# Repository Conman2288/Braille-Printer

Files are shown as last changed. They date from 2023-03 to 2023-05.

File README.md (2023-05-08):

# Braille-Printer
Our project is a personal braille printer with the aim of being one of the cheaper options on the market. The reason that we chose this as our project is because current braille printers cost, on average, over $1,000. By making a more affordable version, we can make braille more accessible for the blind, which is a step towards giving this community a better quality of life. The way that our project works is by using an embosser that moves along a lead screw. This embosser has a set of multiple braille states that are essentially specific bumps that can be switched to on command. A flexible roller is then rolled over the desired state, with the paper in between, in order to emboss the braille onto the paper. The program running on the machine is able to take in a text or pdf file and scan the words in the file. It takes these words and converts them into braille characters, which are then split into their multiple braille states, as each character is made up of two different states. These braille states are then sent to the printer, where, line by line, the braille characters are embossed into the piece of paper. This all comes together to make a device that can receive text input and subsequently print out braille characters, making braille printing accessible at a lower cost than is currently on the market.

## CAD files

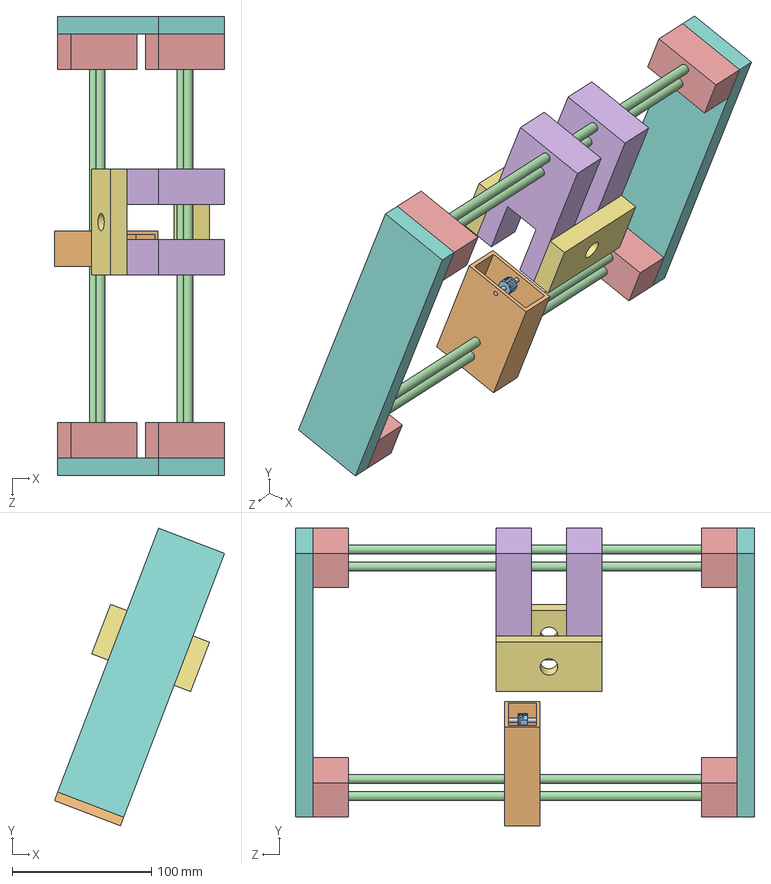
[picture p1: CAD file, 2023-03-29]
Version 2/Final Assembly 2.0.SLDASM
122.4 x 214.1 x 330.2 mm
Roller Axle 2.0
Roller Holder 2.0
Braile Roller 2.0
Leadscrew 2.0 x 4
Pillow Block 2.0 x 4
Wheel Holder 2.0 x 2
Shoulder Bearing 2.0 x 2
Main Holder x 2

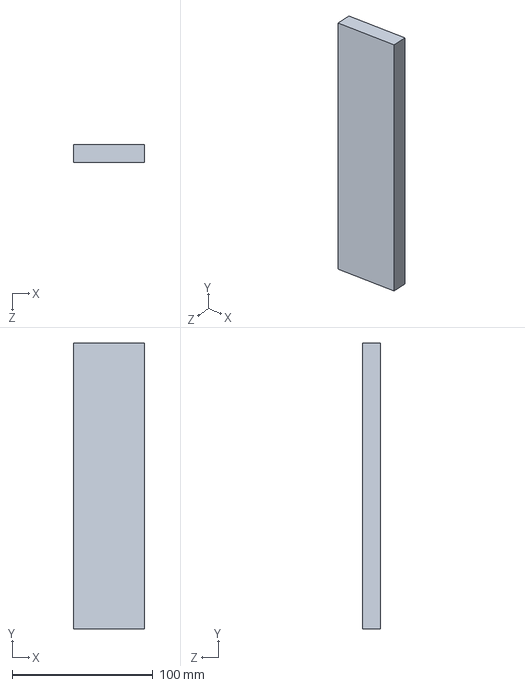
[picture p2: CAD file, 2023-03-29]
Version 2/Main Holder.SLDPRT
50.8 x 203.2 x 12.7 mm

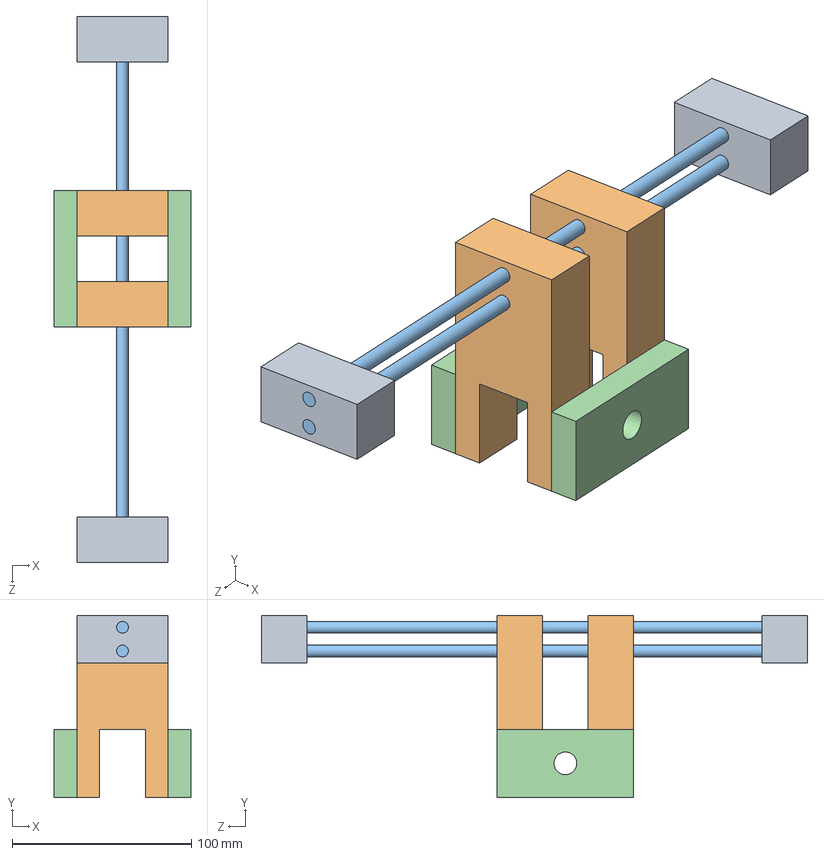
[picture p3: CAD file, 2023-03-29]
Version 2/Wheel assembly 2.0.SLDASM
76.2 x 101.6 x 304.8 mm
Pillow Block 2.0 x 2
Wheel Holder 2.0 x 2
Leadscrew 2.0 x 2
Shoulder Bearing 2.0 x 2

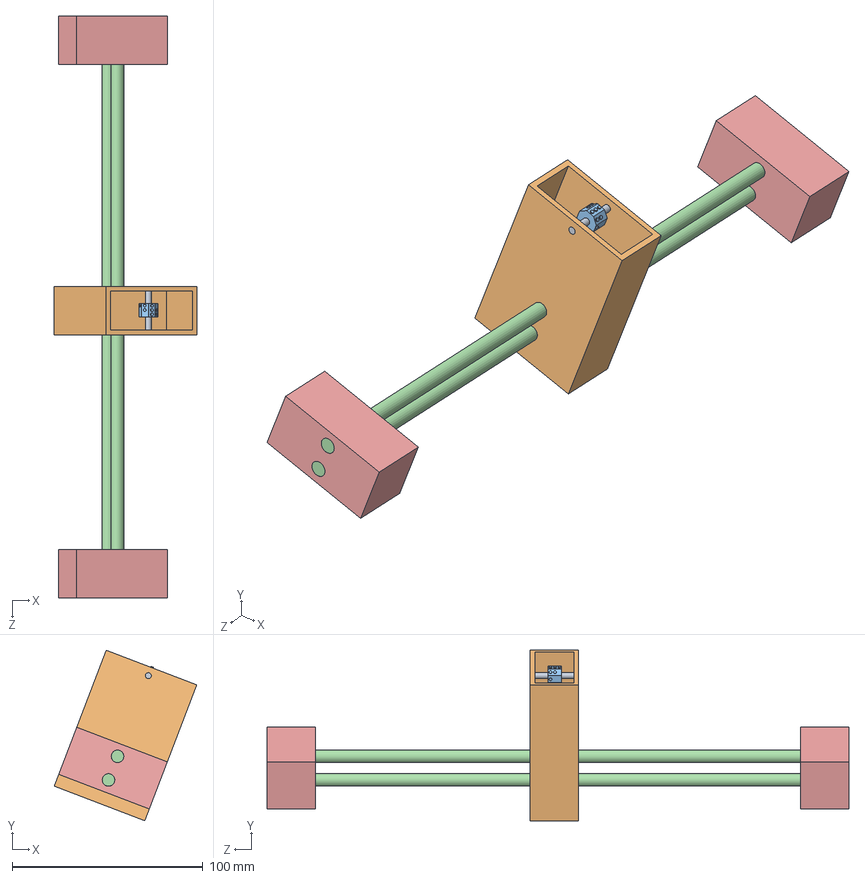
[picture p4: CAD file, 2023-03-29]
Version 2/Presser Assambly.SLDASM
74.7 x 89.3 x 304.8 mm
Roller Axle 2.0
Roller Holder 2.0
Braile Roller 2.0
Leadscrew 2.0 x 2
Pillow Block 2.0 x 2

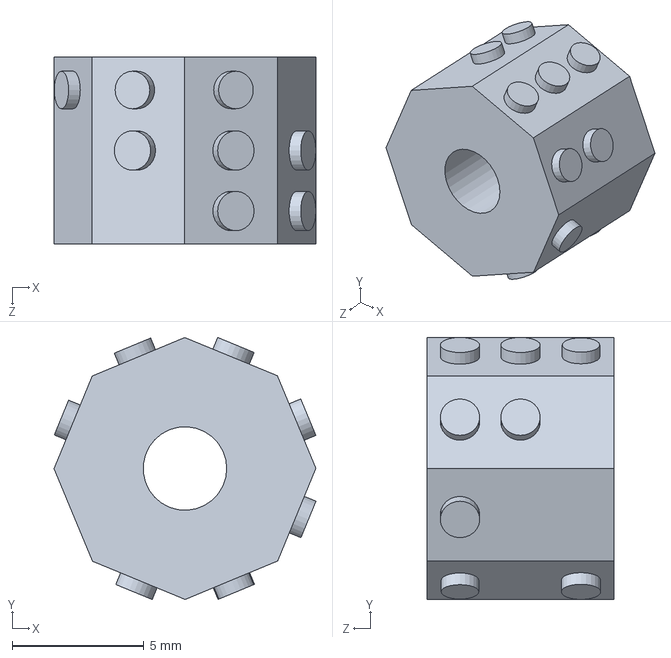
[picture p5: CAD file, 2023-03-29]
Version 2/Braile Roller 2.0 .SLDPRT
9.96 x 9.96 x 7.10 mm

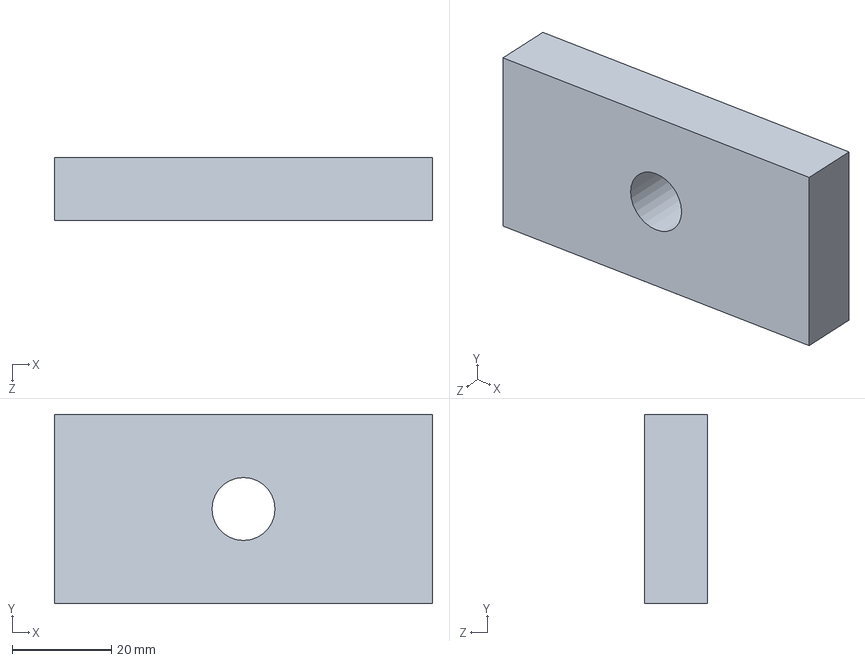
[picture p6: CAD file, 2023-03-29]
Version 2/Shoulder Bearing 2.0.SLDPRT
76.2 x 38.1 x 12.7 mm

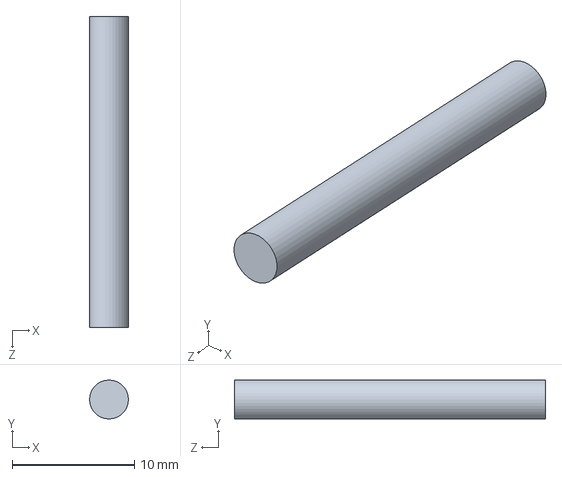
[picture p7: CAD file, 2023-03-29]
Version 2/Roller Axle 2.0.SLDPRT
3.17 x 3.17 x 25.4 mm

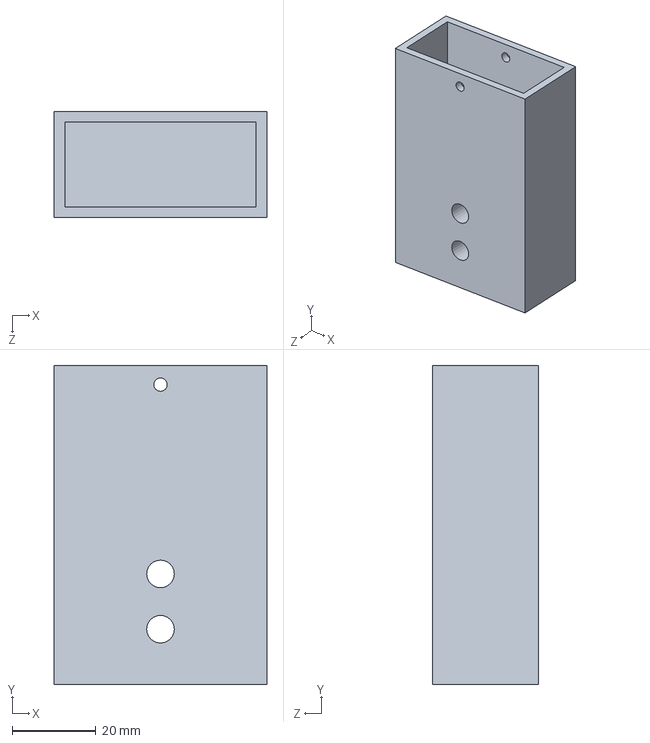
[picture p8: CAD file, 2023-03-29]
Version 2/Roller Holder 2.0.SLDPRT
50.8 x 76.2 x 25.4 mm

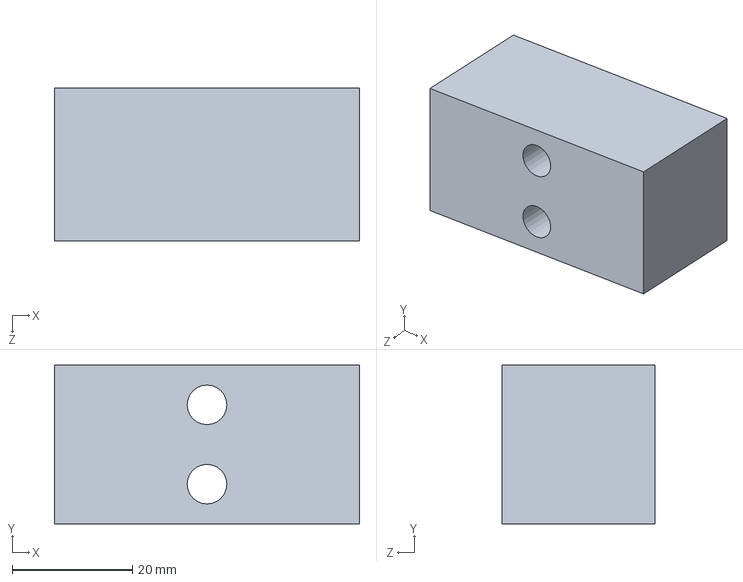
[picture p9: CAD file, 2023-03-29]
Version 2/Pillow Block 2.0.SLDPRT
50.8 x 26.4 x 25.4 mm

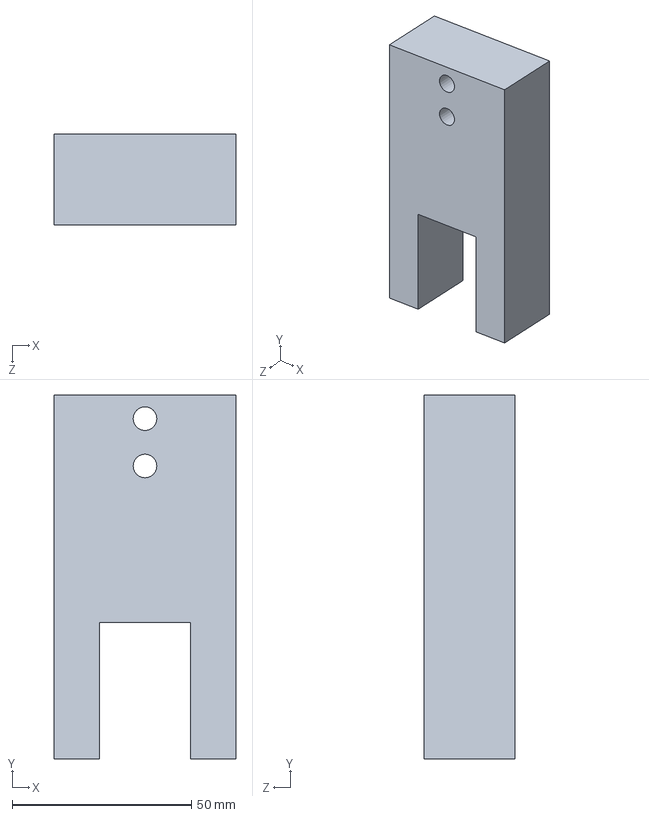
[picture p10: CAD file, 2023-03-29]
Version 2/Wheel Holder 2.0.SLDPRT
50.8 x 101.6 x 25.4 mm

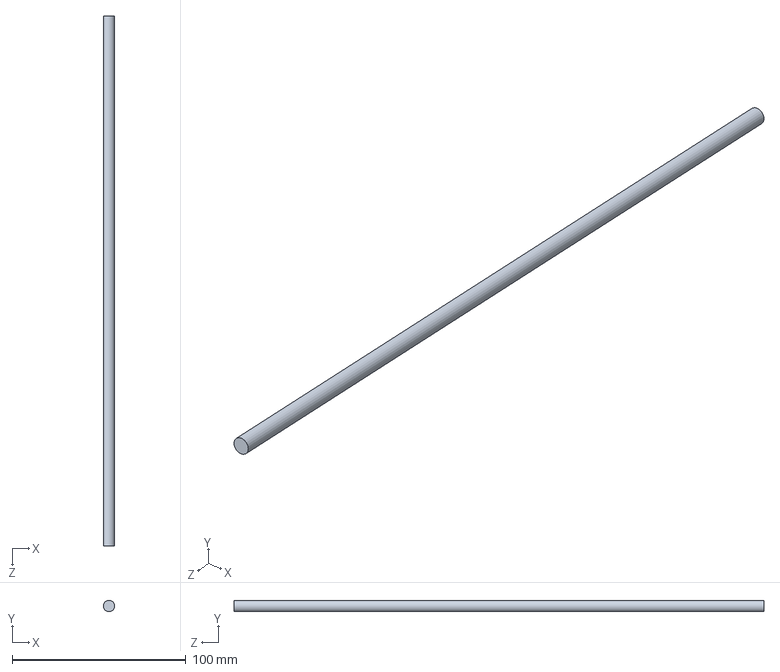
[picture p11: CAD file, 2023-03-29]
Version 2/Leadscrew 2.0.SLDPRT
6.60 x 6.60 x 304.8 mm

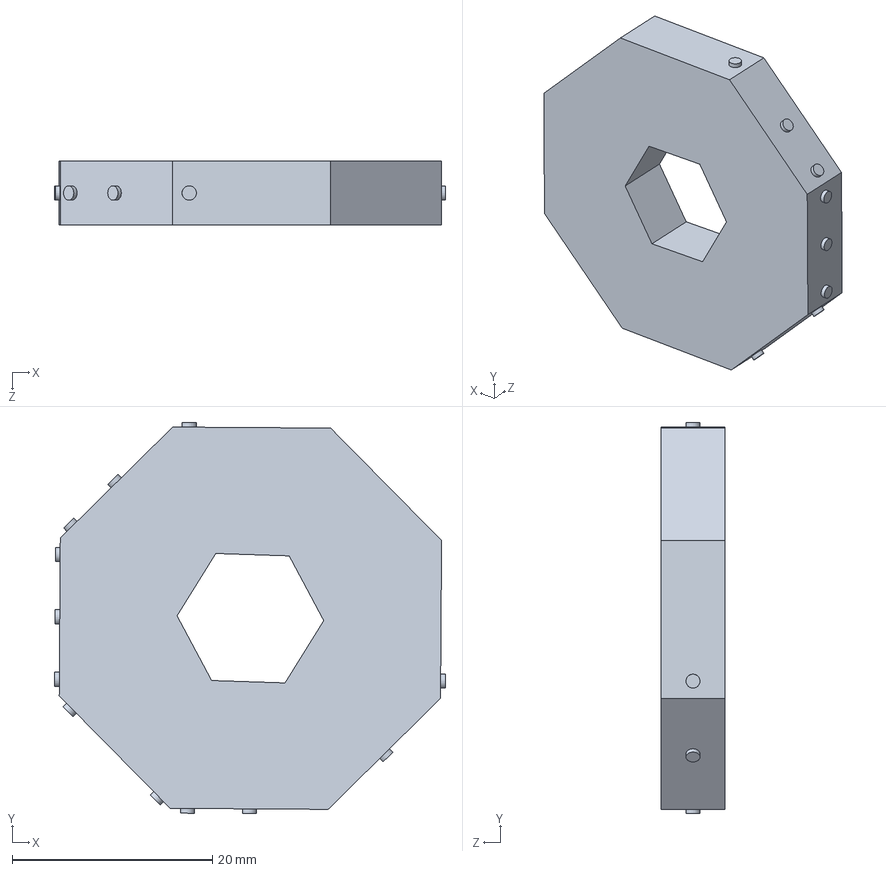
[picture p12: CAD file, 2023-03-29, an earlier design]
Version 1/BraillePresser Part 1.SLDPRT
39.1 x 39.1 x 6.35 mm

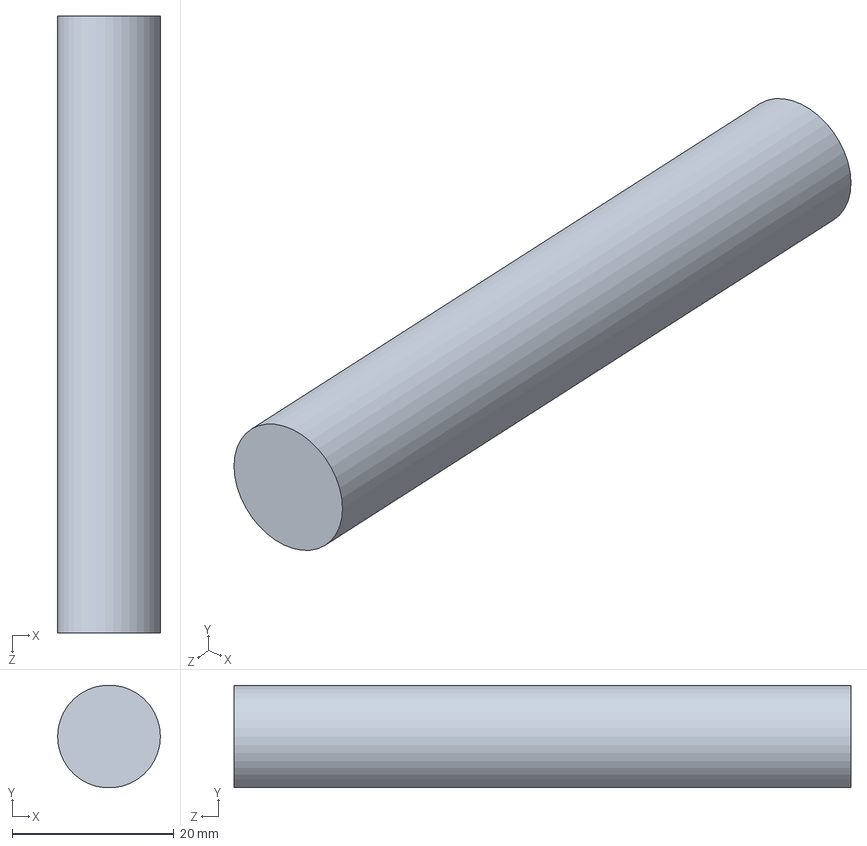
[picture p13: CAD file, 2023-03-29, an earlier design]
Version 1/Wheel Axle.SLDPRT
12.7 x 12.7 x 76.2 mm

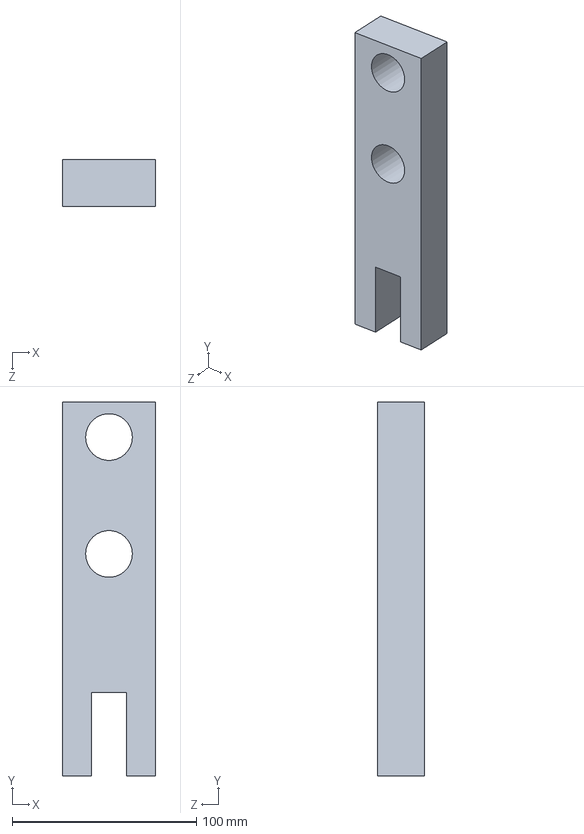
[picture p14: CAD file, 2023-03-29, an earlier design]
Version 1/Wheel holder.SLDPRT
50.8 x 203.2 x 25.4 mm

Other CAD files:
Version 1/Side plate wheel.SLDPRT
Version 1/Initial Assembly - Leadscrew portion.SLDASM
Version 1/leadscrew.SLDPRT
Version 1/Leadscrew Holder.SLDPRT
Version 2/Braile Roller 2.0 .STL

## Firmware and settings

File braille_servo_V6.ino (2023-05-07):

#include <Servo.h>

Servo servo;
int servo_pin = 3;
int motor_pin = 5;
int servo_rotation_count = 0; // variable to count the number of times the servo has rotated
int enA = 7;         // Motor connections
int in1 = 8;
int in2 = 9;
int in3 = 10;
int in4 = 11;
int enB = 12;
bool servo_moved = false; // boolean variable to keep track of whether the servo has moved
bool roller_setup = true;

void move_emb_left(){
    digitalWrite(in1, LOW); // moves embosser to left a character
    digitalWrite(in2, HIGH);
    delay(1850);
}

void move_emb_right(){
    digitalWrite(in1, HIGH); // moves the embosser to the right a character
    digitalWrite(in2, LOW);
    delay(1850);
}

void all_left(){
    digitalWrite(in1, LOW); // moves embosser from right margin to left 
    digitalWrite(in2, HIGH);
    delay(42000);
}

void all_right(){
    digitalWrite(in1, HIGH); // moves embosser from left margin to right
    digitalWrite(in2, LOW);
    delay(42000);
}

void stop_emb(){
    digitalWrite(in1, LOW); // stops the embosser
    digitalWrite(in2, LOW);
}


void move_up(){
    digitalWrite(in3, HIGH); // moves the embosser vertically up
    digitalWrite(in4, LOW);
    delay(250);
}

void move_down(){
    digitalWrite(in3, LOW); // moves the embosser into the paper
    digitalWrite(in4, HIGH);
    delay(250);
}

void stop_press(){
    digitalWrite(in3, LOW); // stops the presser
    digitalWrite(in4, LOW);
}

void setup() {
  // initialize serial communication
  Serial.begin(9600);

  // attach servo to pin
  servo.attach(servo_pin);

  // set motor pin as output
  pinMode(motor_pin, OUTPUT);

  // set pin 5 as output
  pinMode(5, OUTPUT);


}

void loop() {
  if (roller_setup){
    digitalWrite(motor_pin, HIGH); // activate motor pin
    delay(2000); // delay for a short period of time
    digitalWrite(motor_pin, LOW); // deactivate motor pin
    delay(1200); // delay for a short period of time
    roller_setup = false;
  }
  
  // wait for input from Python program
  if (Serial.available() > 0) {
    // read input from Python program
    String input = Serial.readString();
  
    // if input is a position, move servo to that position
    if (input.toInt() >= 0 && input.toInt() <= 180) {
      // move servo to desired position
      servo.write(input.toInt());
      delay(400);
      
      // increment servo rotation count
      servo_rotation_count++;

      // check if the servo has rotated 20 times
      if (servo_rotation_count == 20) {
        digitalWrite(motor_pin, HIGH); // activate motor pin
        delay(950); // delay for a short period of time
        digitalWrite(motor_pin, LOW); // deactivate motor pin
        delay(950); // delay for a short period of time
        servo_rotation_count = 0;
        all_right(); // Moves the embosser back to left margin
      }

      // execute other functions
      analogWrite(enA, 255);
      analogWrite(enB, 255);
      move_emb_left();
      stop_emb();

     if (input.toInt() != 0){ // moves the embosser up and down into the paper
      move_down();
      stop_press();
      move_up();
      stop_press();
      }
    }
  }
}

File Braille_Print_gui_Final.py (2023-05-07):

import sys
import os.path

# Import library to allow communication
# with Arduino
import serial
import time

# Imports a py library to process pdf files
import PyPDF2

# Pyqt5 gui library
from PyQt5.QtWidgets import *
from PyQt5.QtCore import *
from PyQt5.QtGui import *
from PyQt5.QtCore import QThread, pyqtSignal


# import braille library
from pybraille import convertText

# voice assistant module
import pyttsx3

# Variable to set DEBUG mode
DEBUG = True

#########################################################################################
# The Embosser class holds the states associated with each letter in braille
# and the behaviors of this class are the physical change in state of the servo
# based on the angle sent to the receiving Arduino
class Embosser:

    def __init__(self):
        self.state_dictionary = {'A': '10', 'B':'40', 'C':'11', 'D':'14', 'E':'12', 'F':'41',
                                'G':'44', 'H':'42', 'I':'21', 'J':'24', 'K':'60', 'L':'70',
                                'M':'61', 'N':'64', 'O':'62', 'P':'71', 'Q':'74', 'R':'72',
                                'S':'51', 'T':'54', 'U':'63', 'V':'73', 'W':'27', 'X':'66',
                                'Y':'67', 'Z':'65', ',':'20', ';':'50', ':':'22', '.':'25',
                                 '?':'53', '!':'52', '\'':'30', '-':'33', ' ':'00', '1':'10',
                                 '2':'40', '3':'11', '4':'14', '5':'12', '6':'41', '7':'44',
                                 '8':'42', '9':'21', '0':'24'}

        self.state_time = 4.5
        self.state_count = 0
        
    def state0(self):
        # this state passes since no dots are printed
        print("state 0")
        ser.write(bytes(str(0), "ascii"))
        # wait for a short time to allow the servo motor to move
        time.sleep(self.state_time)
    
    def state1(self):
        print("state 1")
        ser.write(bytes(str(144.57), 'ascii'))

        # wait for a short time to allow the servo motor to move
        time.sleep(self.state_time)

    def state2(self):
        print("state 2")
        ser.write(bytes(str(170.28), 'ascii'))

        # wait for a short time to allow the servo motor to move
        time.sleep(self.state_time)

    def state3(self):
        print("state 3")
        ser.write(bytes(str(90.1423), 'ascii'))

        # wait for a short time to allow the servo motor to move
        time.sleep(self.state_time) 

    def state4(self):
        print("state 4")
        ser.write(bytes(str(118.6), 'ascii'))

        # wait for a short time to allow the servo motor to move
        time.sleep(self.state_time)

    def state5(self):
        print("state 5")
        ser.write(bytes(str(59.428), 'ascii'))

        # wait for a short time to allow the servo motor to move
        time.sleep(self.state_time)

    def state6(self):
        print("state 6")
        ser.write(bytes(str(8), 'ascii'))

        # wait for a short time to allow the servo motor to move
        time.sleep(self.state_time)

    def state7(self):
        print("state 7")
        ser.write(bytes(str(33.7143), 'ascii'))

        # wait for a short time to allow the servo motor to move
        time.sleep(self.state_time)

    # This function takes in the data and then processes each string and its two associated states
    # based on the key-value pair in the state dictionary. Every 5 states processed, the roller
    # is then activated to move the paper up a line.
    def process_data(self, data):
        # Placeholder variable for the braille exception of numbers
        consecutive_numbers = False
        data = data.upper()
        key_list = list(self.state_dictionary.keys())
        print("There should be {} states for this print.".format(2*len(data)))
        for s in data:
            if (DEBUG):
                print("Printing [{}, {}]".format(s, convertText(s.lower())))

            # Every 20 characters the paper moves up a line via the roller
            if (self.state_count == 20 and self.state_count != 0):
                print("roller moving")
                time.sleep(2.5)
                self.state_count = 0
                print("moving embosser to all the way left")
                time.sleep(48);

            # If the input data is a number, then a special character
            # is inserted in the braille to distinguish the numbers
            # from other letter configurations.
            if (s.isnumeric() and consecutive_numbers == False):
                print("Printing Number Signifier")
                self.state_count += 2
                self.state3()
                self.state7()
                consecutive_numbers = True

            if (not s.isnumeric()):
                consecutive_numbers = False
                
            self.state_count += 1
            print("Count = {}".format(self.state_count))
            
            if s in key_list:
                if (self.state_dictionary[s].startswith('0')):
                    self.state0()
                elif (self.state_dictionary[s].startswith('1')):
                    self.state1()
                elif (self.state_dictionary[s].startswith('2')):
                    self.state2()
                elif (self.state_dictionary[s].startswith('3')):
                    self.state3()
                elif (self.state_dictionary[s].startswith('4')):
                    self.state4()
                elif (self.state_dictionary[s].startswith('5')):
                    self.state5()
                elif (self.state_dictionary[s].startswith('6')):
                    self.state6()
                elif (self.state_dictionary[s].startswith('7')):
                    self.state7()
                else:
                    pass

                if (self.state_count == 20 and self.state_count != 0):
                    print("roller moving")
                    time.sleep(2.5)
                    self.state_count = 0
                    print("moving embosser to all the way left")
                    time.sleep(48);
                
                self.state_count += 1
                print("Count = {}".format(self.state_count))
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

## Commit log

2023-04-12 Add files via upload
    Basic Template for the Braille Printer GUI
2023-04-20 Add files via upload
    Now has the ability to control the embosser servo
